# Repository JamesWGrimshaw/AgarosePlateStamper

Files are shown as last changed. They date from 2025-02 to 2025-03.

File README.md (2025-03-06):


# AgarosePlateStamper
This set of tools allow for immobilisation of bacterial cells at the bottom of plates for high content microscopy. These consist of a plate stamp, a centering frame, an agarose mould and a cutter.

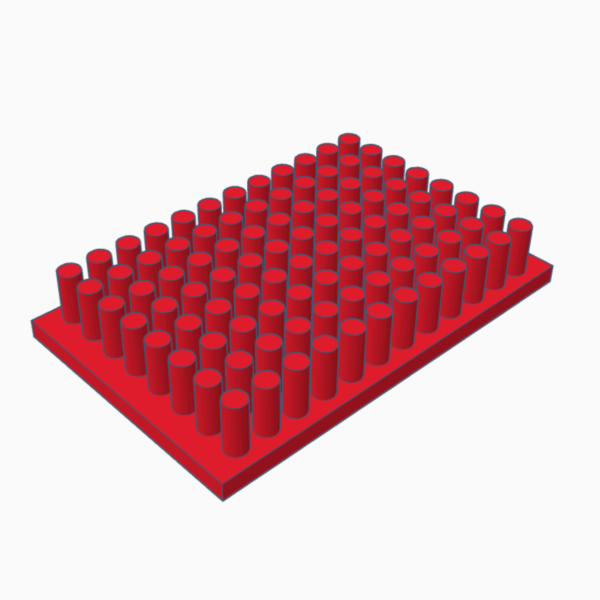
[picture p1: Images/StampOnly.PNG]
Stamp

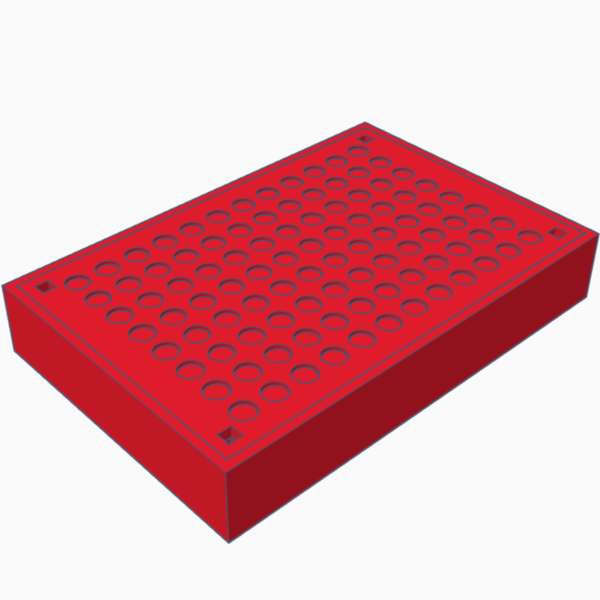
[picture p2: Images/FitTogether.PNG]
Fit Together

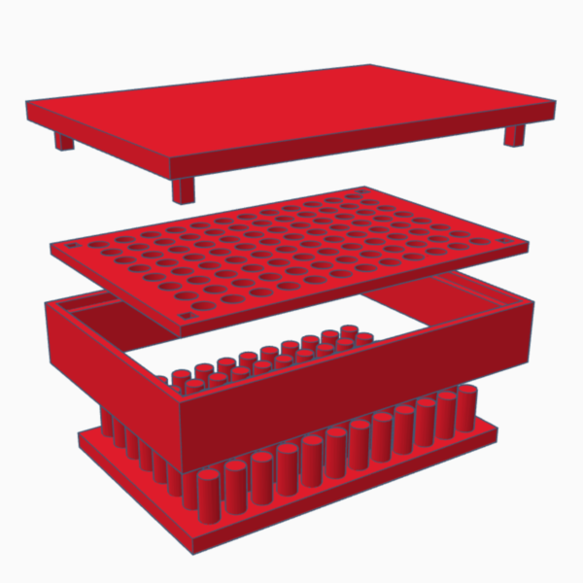
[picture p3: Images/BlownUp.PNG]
Blown Up

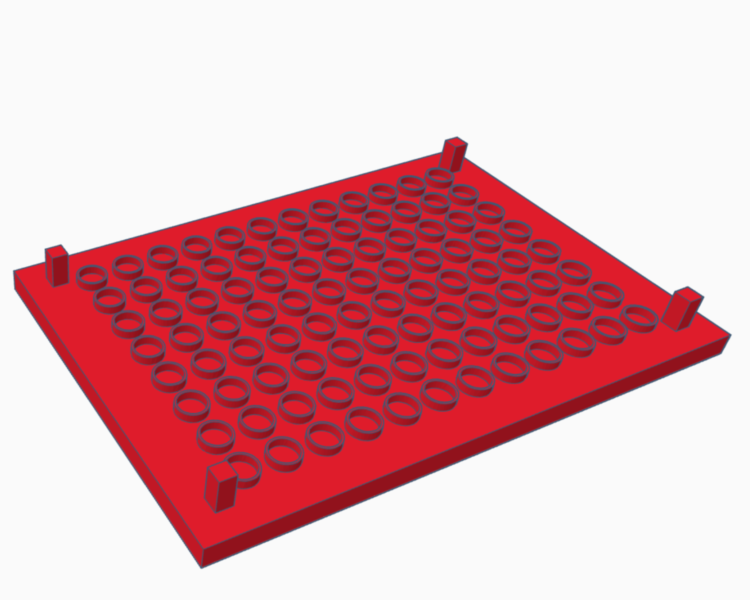
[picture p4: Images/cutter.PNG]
Cutter


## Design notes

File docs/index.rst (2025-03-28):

.. include:: ../README.rst

Agarose Plate Stamper
=====================

**agaroseplatestamper** is a Python library which can generate tools
to allow for immobolisation of bacteria in multi-well plates for microscopy.

Check out the :doc:`usage` section for further information, including :ref:`installation` of the project.

.. note::

   This project is under active development.

Contents
--------

.. toctree::

   :maxdepth: 2

   user/index.rst
   developer/index.rst

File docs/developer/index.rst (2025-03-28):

.:

************
Developers's Guide
************

Welcome to the developer guide for the ``Agarose Plate Stamper``.

.. toctree::
   :maxdepth: 2

   usage
   api

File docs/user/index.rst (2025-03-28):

.:

************
User's Guide
************

Welcome to the user guide for the ``Agarose Plate Stamper``.

.. toctree::
   :maxdepth: 2

   protocol
   gui_guide

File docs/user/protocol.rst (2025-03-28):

Using the Agarose Plate Stamper
===============================

.. _model_selection:

Selecting your models
----------------------

First, select the appropriate models for your plate. The models are stored in the `stls` directory and are within
subdirectories that correspond to the plate type. For example, the models for the ibidi 96 well plate with round wells are 
stored in the `ibidi µ-Plate 96 Well Round` directory. Each plate should include the following models:

- `plate.stl`: An example of the plate itself generated by the software.
- `mould.stl`: A mould that is used to cast the agarose pads that will be loaded and placed into the wells.
- `stamp.stl`: The stamp that will be used to drive the agarose pads into the wells.

In addition, the folder will contain the manufactuer supplied technical drawings for the plate. These are used to generate the models
and are useful for checking the dimensions of the plate and if it is compatible for your particular plate type. If there are multiple 
plates compatible with this model, there will also be a text file containing all known compatible plates (if any are missed please
let us know by raising an issue on the GitHub repository).

If none of the already generated plates are compatible, please see the `Generating your own models` section for how to 
create custom models for your particular plate type.

.. _model_printing:

Printing your models
---------------------

Once you have selected the appropriate models for your plate, you can print them using a 3D printer. Initial testing was performed
using a Prusa i3 MK3S+ with a 0.4 mm nozzle and Prusament PLA filament. The models were printed with a 0.2 mm layer height and 20% infill,
with a solid infill threshold area greater than the area of one of your wells (e.g. used 15 mm^2 for the ibidi 96 well plate). This is to 
ensure that the strength of the columns which can break without this infill setting.

However, these models should be compatible with any 3D printing format so please try and share your results!

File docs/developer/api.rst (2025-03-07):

API
===
.. autosummary::
	:toctree:  generated

	platestamper.generator
	platestamper.gui_utils

.. automodapi:: platestamper.generator

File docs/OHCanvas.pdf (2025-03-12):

## Agarose Plate Stamper

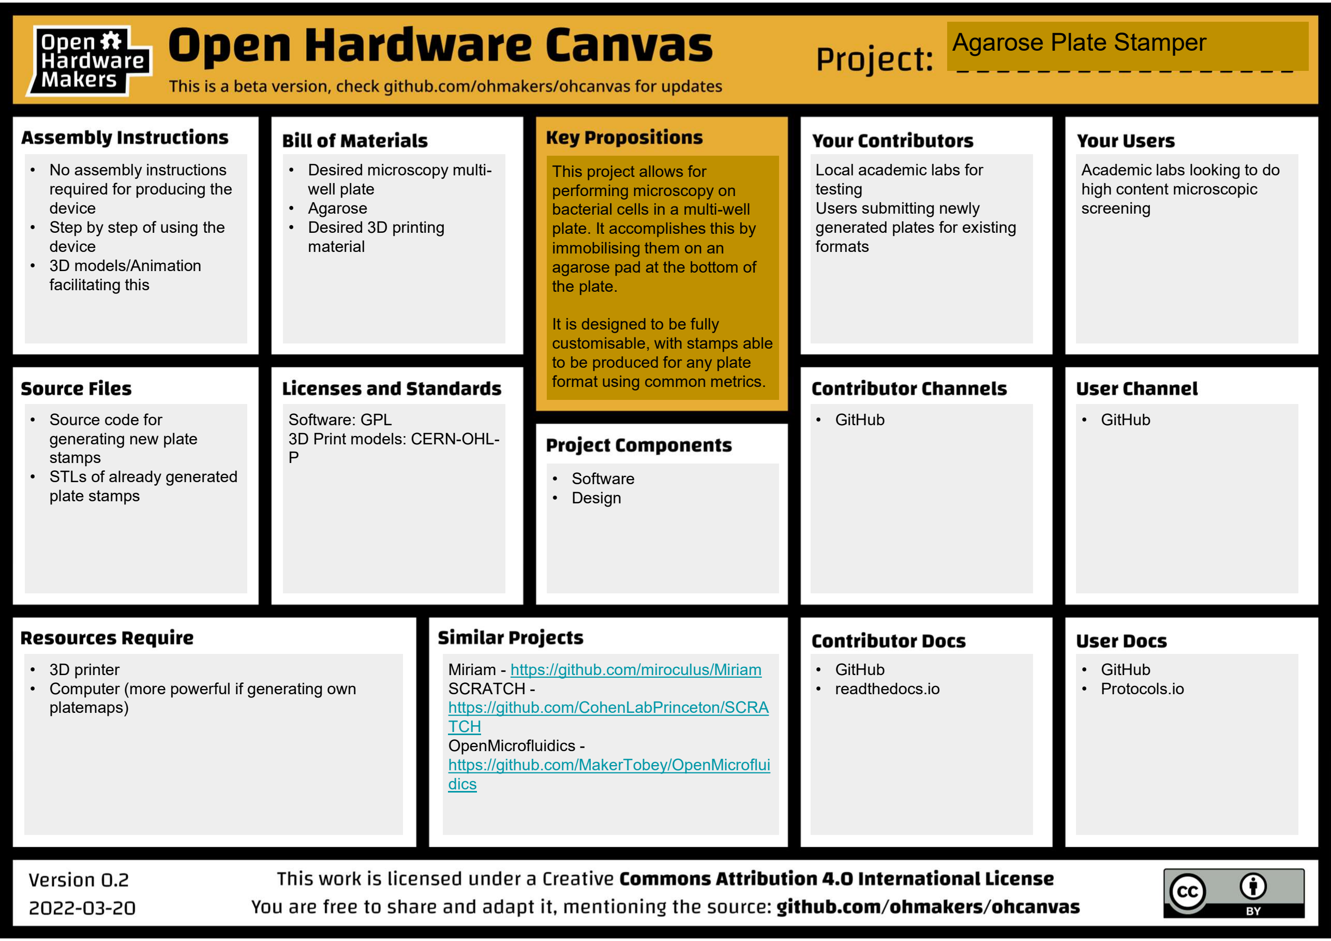
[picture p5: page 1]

- No assembly instructions required for producing the device
- Step by step of using the device
- 3D models/Animation
facilitating this
- Desired microscopy multi-well plate
- Agarose
- Desired 3D printing
material

Local academic labs for
testing
Users submitting newly
generated plates for existing formats

Academic labs looking to do high content microscopic
screening

This project allows for
performing microscopy on
bacterial cells in a multi-well plate. It accomplishes this by immobilising them on an
agarose pad at the bottom of the plate.

It is designed to be fully customisable, with stamps able to be produced for any plate format using common metrics.

- Source code for
generating new plate
stamps
- STLs of already generated plate stamps

Software: GPL
3D Print models: CERN-OHL-P
- GitHub | • GitHub
- GitHub
- Protocols.io
- GitHub
- readthedocs.io
- 3D printer
- Computer (more powerful if generating own platemaps)

Miriam - https://github.com/miroculus/Miriam SCRATCH -
https://github.com/CohenLabPrinceton/SCRA TCH
OpenMicrofluidics -
https://github.com/MakerTobey/OpenMicroflui dics
- Software
- Design

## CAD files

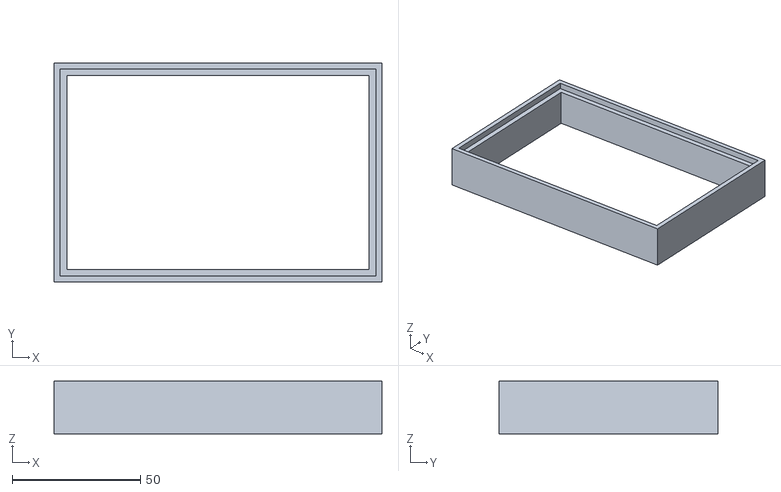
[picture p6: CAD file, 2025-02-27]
stls/ibidi µ-Plate 96 Well Round/Frame.stl
127.8 x 85.5 x 20.5

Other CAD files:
Mould.stl
Stamp.stl

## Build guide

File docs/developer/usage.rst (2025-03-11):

Usage
=====

.. _installation:

Installation
------------

This module is still in early development, so please install directly from the main branch using pip with the following command:

.. code-block:: console

   $ pip install git+https://github.com/JamesWGrimshaw/AgarosePlateStamper.git

.. _Initialising your plate:

Initialising your plate
------------------------

To initialise your plate, you will need to create a new instance of the :class:`multiwell_plate` class giving the 
basic dimensions of the plate which can be found in technical drawings provided by the manufactuer. 
For example here are the technical drawings for the ibidi µ-Plate 96 Well Round:

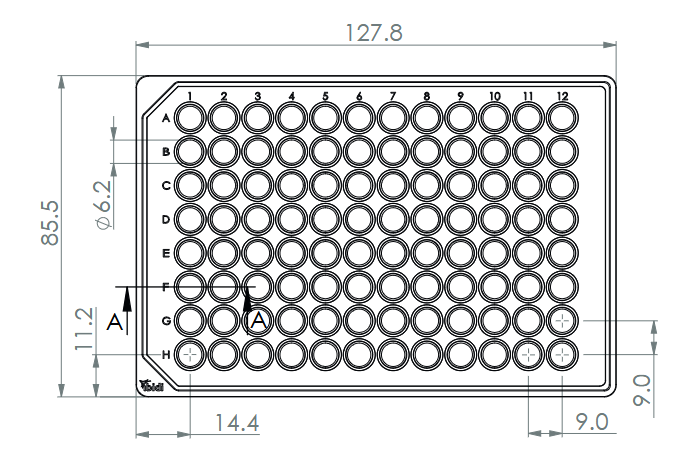
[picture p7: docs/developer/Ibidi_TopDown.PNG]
Ibidi µ-Plate 96 Well Round Technical Drawing (Top Down)
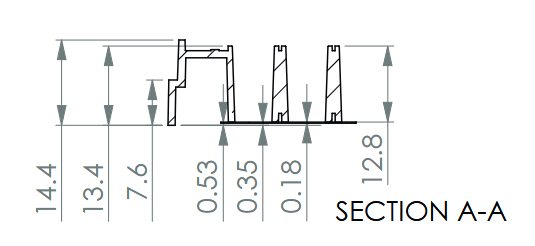
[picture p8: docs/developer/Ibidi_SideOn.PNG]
Ibidi µ-Plate 96 Well Round Technical Drawing (Side On)
 

From the top down view we can see that the plate is 127.8 mm length and 85.5 mm width, has a well diameter 
of 6.2 mm and a well spacing of 9 mm. We can also get the X and Y offsets of the wells from the edges of 
the plate at 14.4 mm for the X offset and 11.2 mm for the Y offset. We can also get the rows and columns 
of the plate which are 8 and 12 respectively.

From the side on view we can see that each well is 13.4 mm deep (excluding the lip around the edge of the plate).

Therefore with this information we can initialise our plate as following:

.. code-block:: python

   from AgarosePlateStamper.generator import multiwell_plate

   plate = multiwell_plate(127.8, # PlateLength
						   85.5, # PlateWidth
						   6.2, # WellDiameter
						   9, # WellToWellDistance
						   13.4, # WellDepth
						   14.4, # WellXOffset
						   11.2, # WellYOffset
						   8, # Rows
						   12 # Columns
						  )

These are the essential components of the plate for initialisation, however there are other optional parameters that can be set.
In order to export the generated models you will need to have OpenSCAD installed on your system and the path to the OpenSCAD executable
set in the `OpenSCADPath` parameter. To install OpenSCAD please visit the following link: https://openscad.org/downloads.html

You may also want to increase the number of segments used to generate the well geometry, this can be done by setting the `CylinderSegments` parameter.
If we have both of these set we can initialise our plate as follows:

.. code-block:: python

   plate = multiwell_plate(127.8, # PlateLength
						   85.5, # PlateWidth
						   6.2, # WellDiameter
						   9, # WellToWellDistance
						   13.4, # WellDepth
						   14.4, # WellXOffset
						   11.2, # WellYOffset
						   8, # Rows
						   12, # Columns
						   OpenSCADPath="C:/Program Files/OpenSCAD/OpenSCAD.exe", # Path to OpenSCAD executable
						   CylinderSegments=256 # Number of segments to use for the well geometry
						  )

There are many additional parameters that can be set allowing you to tune the print to your specific needs. For a full list of parameters please see the :class:`multiwell_plate` class documentation.

.. _Exporting your models:
Exporting your models
---------------------

Once you have initialised your plate you can generate the models and export them using the `export_object` method.
You can export the models in either the scad format or stl format. When exporting in the stl format it will likely 
take longer to export the models, especially if you have a high number of `CylinderSegments` set. It is often worth
setting a lower number of `CylinderSegments` when prototyping and then increasing the number when you are ready 
to export the final models.

For example, to export both the stamp and the mould you can use the following code:

.. code-block:: python

   plate.PlateStamp.export_object("Stamp.stl", stl=True)
   plate.PlateMould.export_object("Mould.stl", stl=True)

You may also want to quickly visualise the models while prototyping, this can be done with the `render` method:

.. code-block:: python

   plate.PlateStamp.render()





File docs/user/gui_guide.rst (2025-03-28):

Generating your own models
==========================

.. _gui installation:

GUI Installation
----------------

GUI development is still in progress

.. _gui usage:

GUI Usage
---------

GUI development is still in progress

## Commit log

2025-02-27 Update and rename Insert_NoBrim.stl to Mould.stl
    [Mould.stl]
2025-02-27 Update and rename Topper_Frame_NoBrim_v1.4.stl to Frame.stl
    [Frame.stl]
2025-02-27 Update and rename Mould.stl to Stamp.stl
    [Stamp.stl]
2025-02-27 rename and reupload
    [Frame.stl]
2025-03-07 retrying docs
    [Frame.stl]
2025-03-28 update to docs
    [Frame.stl]
